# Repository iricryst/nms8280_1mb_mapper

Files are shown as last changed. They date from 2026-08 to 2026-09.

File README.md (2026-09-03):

# nms8280_1mb_mapper

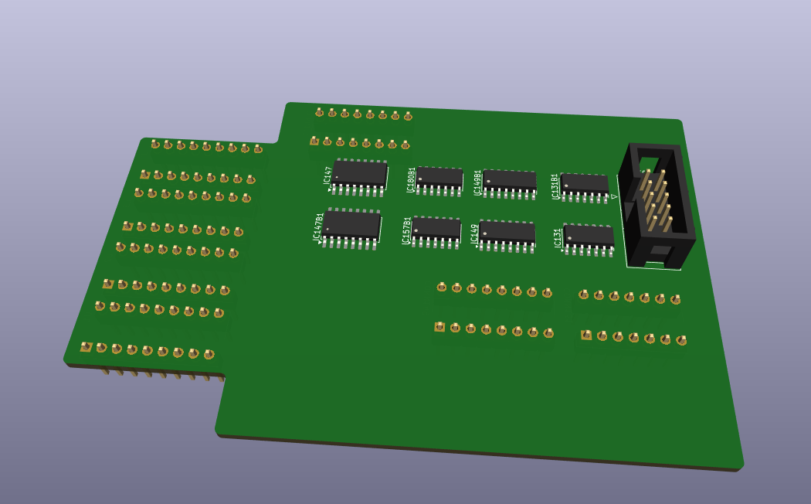
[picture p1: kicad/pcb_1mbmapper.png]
1MB mapper PCB


Project to document and create a 1MB module for a Philips NMS8280 MSX. Based on a paper by Hans Oranje.

This project is far from production ready. It is only a concept. I wouldn't even call it a proof of concept. 

## Reference documents

- [1MB PC SIMM by Hans Oranje](./1mbnms8280e.pdf)
- [Philips NMS 8280 Service Manual](./Philips%20NMS%208280%20Service%20Manual.pdf)

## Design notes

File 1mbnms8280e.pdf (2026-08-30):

# 1 MB PC-SIMM in NMS 8280

## Update your NMS8250/55/80 to 1Mb memory

## Hans Oranje, 2002 English translation by HansO, 2003

Required parts

Part | Usage
1 x 74LS670 | mapper use D4 and D5 for MA18 and MA 19 the existing 74LS670 creates the extra
MA17 with D3
1 x 74LS125 | backannotation on D3, D4 and D5
1 x 74LS08 | cas2/e
1 x 74LS00 | don't write while refresh
1 x 74LS157 | Create L8 and L9 from MA16- MA17 and MA18-MA19
1 x 30 pin 3 chip | 414400 x 2, 414100 x 1 PC SIMM

### Preparations

Take the motherboard carefully out of the housing

Remove IC 133 - IC 136 ( 41464 ) near the VDP. Best is to cut the pins and remove the remains Remove R 127 and R 128 ( both 100 ohm ) in the neighbourhood IC 131 ( 74LS125).

Prepare the following IC’s:

74LS670 : cut the pins 1, 2, 3, 6, 7, 9, 10 and 15 half.
74LS125 : cut the pins 2, 3, 5, 6, 8, 9, 11 t/m 13 half
74LS08 | : cut the pins 1 t/m 6 and 8 t/m 13 half
74LS00 | : cut the pins 1 t/m 6 and 8 t/m 13 half.
74LS157 : cut the pins 2 t/m 7 and 9 t/m 14 half.

### Insert IC’s

Insert the 74LS670 | on top of IC 149 (74LS670) | and is now called IC 149B.
Insert the 74LS125 | on top of IC 131 (74LS125) | and is now called IC 131B.
Insert the 74LS08 | on top of IC 157 (74LS00) | and is now called IC 157B.
Insert the 74LS00 | on top of IC 180 (74LS32) | and is now called IC 180B.
Insert the 74LS157 | on top of IC 147 (74LS157) | and is now called IC 147B.

Solder all remaining whole pins to the IC pins underneath.

Attach a wire to IC 131B (74LS125) between pin 13 and pin 1.

Attach a wire to IC 157B (74LS08) between pin 14, pin 13 and pin 12. Attach a wire to IC 157B (74LS08) between pin 11, pin 10 and pin 9.

Attach a wire to IC 180B (74LS00) between pin 14, pin 13 and pin 12.
Attach a wire to IC 180B (74LS00) between pin 11, pin 10 and pin 9.
Attach a wire to IC 180B (74LS00) between pin 3 and pin 4.
Attach a wire to between pin 12 IC 180 (74LS32) and pin 1 and 2 of IC 180B (74LS00) (RFSH).
Attach a wire to between R 130 ( 100 ohm, on the side of the Video RAM ) and pin 5 of IC 180B (74LS00) (WE).

Attach a wire between printspot R 128 ( zijthe RAM) and pin 3 of IC 157B (74LS08) (CAS 0).
Attach a wire between printspot R 127 ( zijthe RAM) and pin 6 of IC 157B (74LS08) (CAS1).
Attach a wire between pin 1 and 4 of IC 157B (74LS08) to pin 2 IC 111 (74LS32) (CAS2/E).
Attach a wire between pin 2 and 5 of IC 157B (74LS08) to pin 6 IC 180B (74LS00).

Attach a wire between pin 7 IC 149 (74LS670) and pin 2 IC 147B (74LS157) (MA16)
Attach a wire between pin 11 of IC 161 (74LS243) and pin 3 of IC 131B (74LS125) and pin 3 of IC 149 (74LS670) (D3).

Attach a wire between pin 2 of IC 131B (74LS125) and pin 6 of IC 149 (74LS670) and pin 3 of IC 147B (74LS157) (MA17).

Attach a wire between pin 15 of IC 149B (74LS670) and pin 6 of IC 131B (74LS125)
and printspot pin 11 of IC 176 (74LS367) (D4).

Attach a wire between pin 5 of IC 131B (74LS125) and pin 10 of IC 149B (74LS670) and pin 5 of IC 147B (74LS157) (MA18).

Attach a wire between pin 1 of IC 149B (74LS670) and pin 8 of IC 131B (74LS125) and printspot pin 13 of IC 176 (74LS367) (D5).

Attach a wire between pin 9 of IC 131B (74LS125) and pin 9 of IC 149B (74LS670) and pin 6 of IC 147B (74LS157) (MA19).

### Placement of the PC SIMM to the bottom of the motherbord

Turn the mainboard to the other side.

Cut all ic pins on the bottom between IC 147 and IC 177 .
Attach double sided sticky paper between the PC-SIMM and the board.

In the next description the wires are soldered directly to the PC SIMM The 2 wires to IC 147B ( 74LS157) are lead to a empty IC hole.

pin Omschrijving | To
30 | Vcc + 5 Volt | IC 133 pin 9
29 | Din(9)
28 | CAS(9)
27 | RAS | IC 133 pin 5
26 | Dout(9)
25 | D7 | IC 133 pin 17
24 | NC
23 | D6 | IC 133 pin 15
22 | Gnd | IC 133 pin 18
21 | WE | IC 133 pin 4
20 | D5 | IC 133 pin 3
19 | NC
18 | L9 | IC 147B pin 7 ( 74LS157)
17 | L8 | IC 147B pin 4 ( 74LS157)
16 | D4 | IC 133 pin 2
15 | L7 | IC 136 pin 10
14 | L6 | IC 136 pin 6
13 | D3 | IC 134 pin 17
12 | L5 | IC 136 pin 7
11 | L4 | IC 136 pin 8
10 | D2 | IC 134 pin 15
09 | Gnd | IC 134 pin 18
08 | L3 | IC 134 pin 11
07 | L2 | IC 134 pin 12
06 | D1 | IC 134 pin 3
05 | L1 | IC 134 pin 13
04 | L0 | IC 134 pin 14
03 | D0 | IC 134 pin 2
02 | CAS | IC 134 pin 16
01 | Vcc + 5 Volt | IC 134 pin 9

Control all wires and soldering points!
When the computer starts normally the modification is very likely succesfull!
When the computer starts it will still tell you that 128K RAM is present, that is the normal behaviour of the ROM and does not tell the modification failed.

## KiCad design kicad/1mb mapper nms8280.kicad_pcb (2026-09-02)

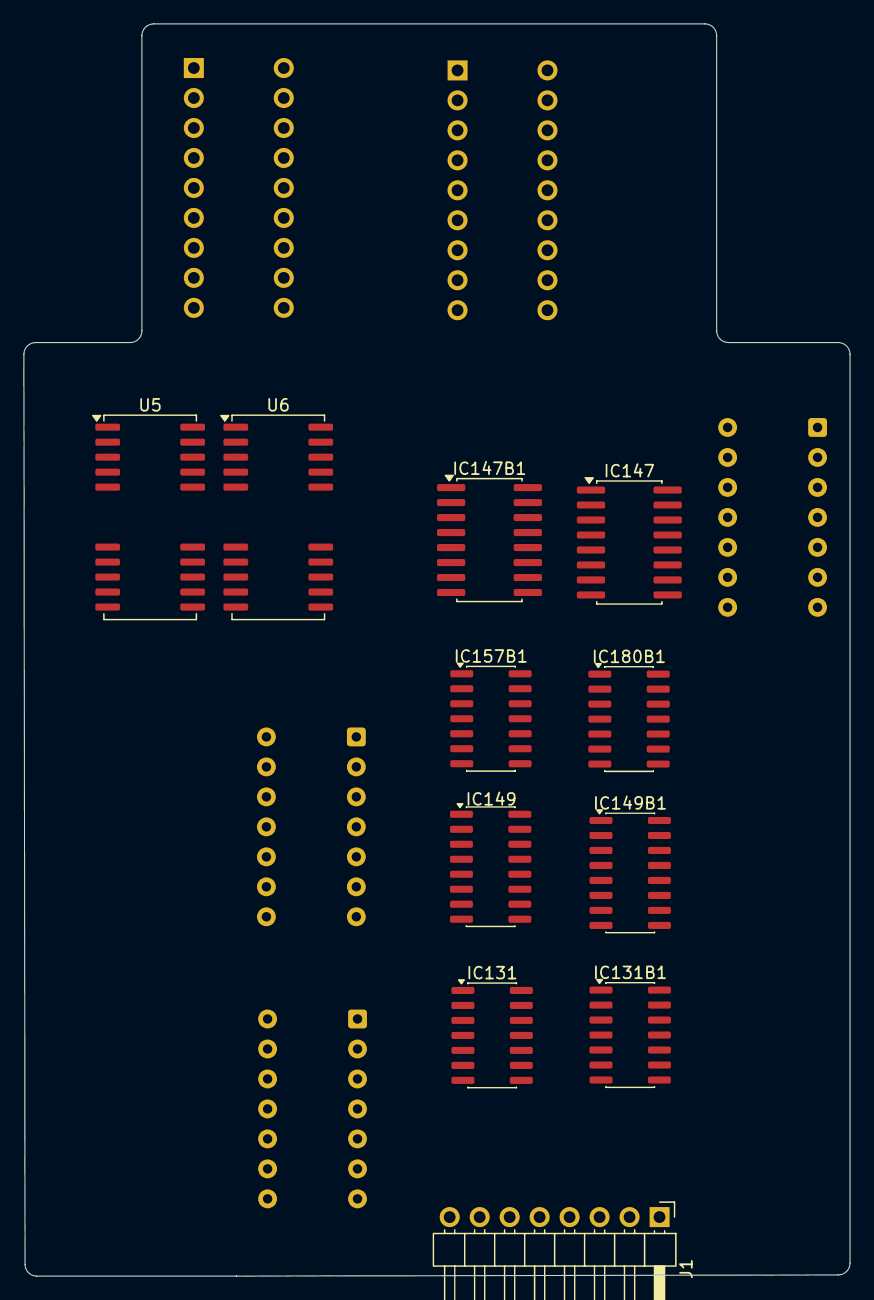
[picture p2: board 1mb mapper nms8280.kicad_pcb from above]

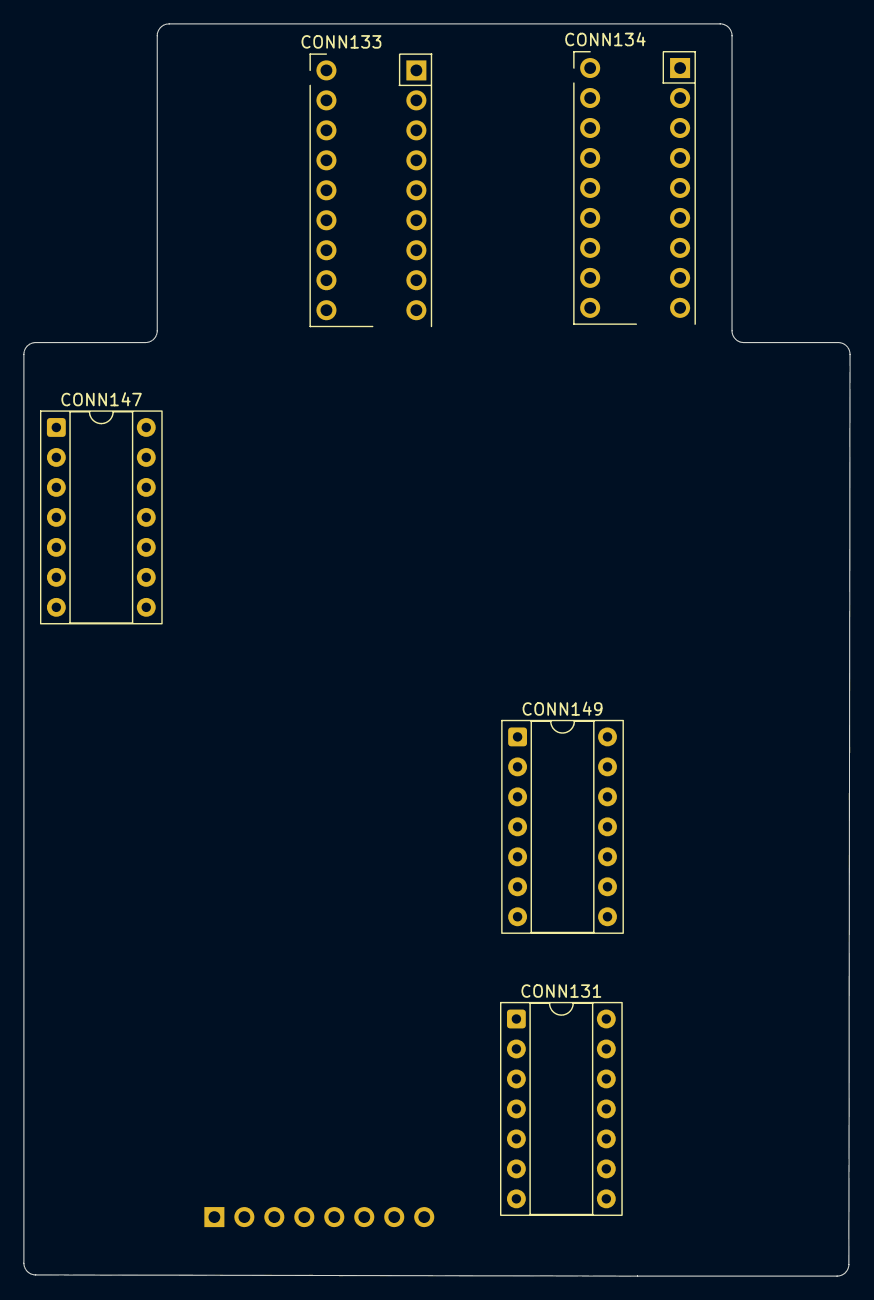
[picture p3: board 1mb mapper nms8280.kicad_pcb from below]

Board: 2 copper layers, 70.0 x 106.1 mm, 16 parts (5 on the bottom side), 70 nets, no tracks yet.

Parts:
CONN131, CONN147, CONN149: DIP-14_W7.62mm_Socket
CONN133, CONN134: PinHeader_2x09_P2.54mm_Vertical
IC131, IC131B1, IC157B1, IC180B1: SOIC-14_3.9x8.7mm_P1.27mm
IC147, IC147B1: 74LS157; SOIC-16W_5.3x10.2mm_P1.27mm
IC149, IC149B1: 74LS670; SOIC-16_3.9x9.9mm_P1.27mm
J1: Conn_01x08_Pin; PinHeader_1x08_P2.54mm_Horizontal
U5, U6: SOJ-26_7.62x18.415mm_P1.27mm

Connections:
/buffer cas section/<NO NET>: IC180B1.1 (1A), IC180B1.2 (1B), J1.1
/buffer cas section/GND: CONN131.7 (GND), CONN147.8 (GND), CONN149.8 (GND), IC131.7 (GND), IC131B1.7 (GND), IC147.8 (GND), IC147B1.8 (GND), IC149.8 (GND), IC149B1.2 (D3), IC149B1.3 (D4), IC149B1.8 (GND), IC157B1.7 (GND), IC180B1.7 (GND)
/buffer cas section/IC131_P1_IC131B: CONN131.1 (1A), IC131.1 (1E), IC131B1.1 (1E), IC131B1.13 (4E)
/buffer cas section/IC131_P2: CONN131.2 (1B), IC131.2 (1D)
/buffer cas section/IC131_P3: CONN131.3 (1Y), IC131.3 (1O)
/buffer cas section/IC131_P4_IC131B: CONN131.4 (2A), IC131.4 (2E), IC131B1.4 (2E)
/buffer cas section/IC131_P5: CONN131.5 (2B), IC131.5 (2D)
/buffer cas section/IC131_P6: CONN131.6 (2Y), IC131.6 (2O)
/buffer cas section/IC131_P8: CONN131.8 (3Y), IC131.8 (3O)
/buffer cas section/IC131_P9: CONN131.9 (3A), IC131.9 (3D)
/buffer cas section/IC131_P10_IC131B: CONN131.10 (3B), IC131.10 (3E), IC131B1.10 (3E)
/buffer cas section/IC131_P11: CONN131.11 (4Y), IC131.11 (4O)
/buffer cas section/IC131_P12: CONN131.12 (4A), IC131.12 (4D)
/buffer cas section/IC131_P13: CONN131.13 (4B), IC131.13 (4E)
/buffer cas section/IC147_P1_IC147B: CONN147.1 (S), IC147.1 (S), IC147B1.1 (S)
/buffer cas section/IC147_P2: CONN147.2 (A0), IC147.2 (I0a)
/buffer cas section/IC147_P3: CONN147.3 (B0), IC147.3 (I1a)
/buffer cas section/IC147_P4: CONN147.4 (Y0), IC147.4 (Za)
/buffer cas section/IC147_P5: CONN147.5 (A1), IC147.5 (I0b)
/buffer cas section/IC147_P6: CONN147.6 (B1), IC147.6 (I1b)
/buffer cas section/IC147_P7: CONN147.7 (Y1), IC147.7 (Zb)
/buffer cas section/IC147_P9: CONN147.9 (Y2), IC147.9 (Zc)
/buffer cas section/IC147_P10: CONN147.10 (B2), IC147.10 (I1c)
/buffer cas section/IC147_P11: CONN147.11 (A2), IC147.11 (I0c)
/buffer cas section/IC147_P12: CONN147.12 (Y3), IC147.12 (Zd)
/buffer cas section/IC147_P13: CONN147.13 (B3), IC147.13 (I1d)
/buffer cas section/IC147_P14: CONN147.14 (A3), IC147.14 (I0d)
/buffer cas section/IC147_P15_IC147B: IC147.15 (E), IC147B1.15 (E)
/buffer cas section/IC149_P1: CONN149.1 (D2), IC149.1 (D2)
/buffer cas section/IC149_P2: CONN149.2 (D3), IC149.2 (D3)
/buffer cas section/IC149_P3: CONN149.3 (D4), IC131B1.3 (1O), IC149.3 (D4), J1.4
/buffer cas section/IC149_P4_IC149B: CONN149.4 (RB), IC149.4 (Rb), IC149B1.4 (Rb)
/buffer cas section/IC149_P5_IC149B: CONN149.5 (RA), IC149.5 (Ra), IC149B1.5 (Ra)
/buffer cas section/IC149_P6: CONN149.6 (Q4), IC131B1.2 (1D), IC147B1.3 (I1a), IC149.6 (Q4)
/buffer cas section/IC149_P7: CONN149.7 (Q3), IC147B1.2 (I0a), IC149.7 (Q3)
/buffer cas section/IC149_P9: CONN149.9 (Q2), IC149.9 (Q2)
/buffer cas section/IC149_P10: CONN149.10 (Q1), IC149.10 (Q1)
/buffer cas section/IC149_P11_IC149B: CONN149.11 (ER), IC149.11 (~Er), IC149B1.11 (~Er)
/buffer cas section/IC149_P12_IC149B: CONN149.12 (EW), IC149.12 (~Ew), IC149B1.12 (~Ew)
/buffer cas section/IC149_P13_IC149B: CONN149.13 (WB), IC149.13 (Wb), IC149B1.13 (Wb)
/buffer cas section/IC149_P14_IC149B: CONN149.14 (WA), IC149.14 (Wa), IC149B1.14 (Wa)
/buffer cas section/Vcc: CONN131.14 (Vcc), IC131.14 (Vcc), IC131B1.14 (Vcc), IC147.16 (VCC), IC147B1.16 (VCC), IC149.16 (VCC), IC149B1.16 (VCC), IC157B1.12 (4A), IC157B1.13 (4B), IC157B1.14 (Vcc), IC180B1.12 (4A), IC180B1.13 (4B), IC180B1.14 (Vcc)
/ram section/A0_IC133/134_P14: U5.9 (A0), U6.9 (A0)
/ram section/A1_IC133/134_P13: U5.10 (A1), U6.10 (A1)
/ram section/A2_IC133/134_P12: U5.11 (A2), U6.11 (A2)
/ram section/A3_IC133/134_P11: U5.12 (A3), U6.12 (A3)
/ram section/A4_IC133/134_P8: U5.14 (A4), U6.14 (A4)
/ram section/A5_IC133/134_P7: U5.15 (A5), U6.15 (A5)
/ram section/A6_IC133/134_P6: U5.16 (A6), U6.16 (A6)
/ram section/A7_IC133/134_P10: U5.17 (A7), U6.17 (A7)
/ram section/CAS_IC133/134_P16: U5.23 (CAS), U6.23 (CAS)
/ram section/GND: CONN133.18 (GND_18), CONN134.18 (GND_18), U5.22 (OE), U5.26 (GND), U6.22 (OE), U6.26 (GND)
/ram section/RAS_IC133_P5: U5.4 (RAS), U6.4 (RAS)
/ram section/WE_IC133_P4: U5.3 (WE), U6.3 (WE)
A8_IC147B_P4: IC147B1.4 (Za), U5.18 (A8), U6.18 (A8)
A9_IC147B_P7: IC147B1.7 (Zb), U5.5 (A9), U6.5 (A9)
unnamed: IC131B1.5 (2D), IC147B1.5 (I0b), IC149B1.10 (Q1)
unnamed: IC131B1.6 (2O), IC149B1.15 (D1), J1.3
unnamed: IC131B1.9 (3D), IC147B1.6 (I1b), IC149B1.9 (Q2)
unnamed: IC131B1.8 (3O), IC149B1.1 (D2), J1.2
unnamed: IC147B1.9 (Zc), IC147B1.10 (I1c), IC147B1.11 (I0c)
unnamed: IC147B1.12 (Zd), IC147B1.13 (I1d), IC147B1.14 (I0d)
unnamed: IC157B1.1 (1A), IC157B1.4 (2A), J1.5
unnamed: IC157B1.2 (1B), IC157B1.5 (2B), IC180B1.6 (2Y)
unnamed: IC157B1.3 (1Y), J1.6
unnamed: IC157B1.6 (2Y), J1.7
unnamed: IC157B1.9 (3A), IC157B1.10 (3B), IC157B1.11 (4Y)
unnamed: IC180B1.3 (1Y), IC180B1.4 (2A)
unnamed: IC180B1.5 (2B), J1.8
unnamed: IC180B1.9 (3A), IC180B1.10 (3B), IC180B1.11 (4Y)

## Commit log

2026-08-30 Initial project import
    [1mb mapper nms8280 version 2.kicad_sch, 1mb mapper nms8280.kicad_pcb, 1mb mapper nms8280.kicad_sch]
2026-08-31 Update KiCad design files from archive
    [1mb mapper nms8280.kicad_sch]
2026-09-02 Update KiCad project from local archive
    [1mb mapper nms8280.kicad_pcb, 1mb mapper nms8280.kicad_sch, ram_section.kicad_sch]
